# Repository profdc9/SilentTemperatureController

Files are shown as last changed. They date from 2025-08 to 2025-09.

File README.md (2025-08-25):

# Silent Temperature Controller

This is a heating temperature controller intended to minimize the vibrations caused by the heating element.  It uses kHz speed PWM modulated DC, rather than switching 50 or 60 cycle mains power, to power the heating elements.  For explosing holographic emulsions, the temperature must be stable and the vibrations must be minimized so that the sub-wavelength interference features are preserved.  By using high frequency PWM, the mechanical vibration or magnetostriction of the heating element coils is raised above a likely resonance frequency and therefore unlikely to cause significant vibrational movement.

The temperature controller can use up to three B3950 10k nominal resistance thermistors, or alternatively a LM335 temperature-based zener diode.  Reference thermistors may be added so that differential measurements can be taken to compensate for component temperature drift.  The controller supports up to four heating elements.  The DC power supply is up to 24 volts and 10 amps or so, with the limitation given by the trace width on the PCB.  If additional power bus wires are soldered in parallel with the traces, a higher current capacity is likely possible.  It is best to place the thermistors and heating elements in a vibration isolated, thermally insulated enclosure in which the hologram is exposed, with the enclosure being small enough so that the heaters can maintain a constant temperature throughout the volume.  A vibration-isolated platform may be achieved by placing a heavy cement slab or granite slab on partially inflated tires, and the granite slab may be made part of a thermally insulated enclosure using polystryrene slabs as walls.

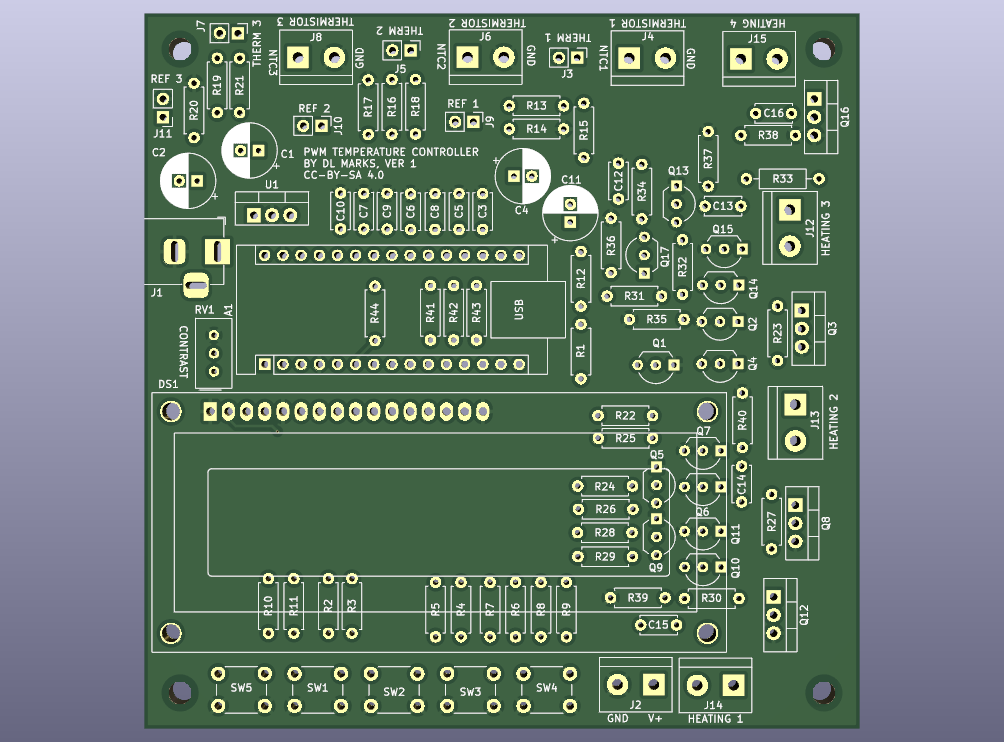
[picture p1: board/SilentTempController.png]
PCB


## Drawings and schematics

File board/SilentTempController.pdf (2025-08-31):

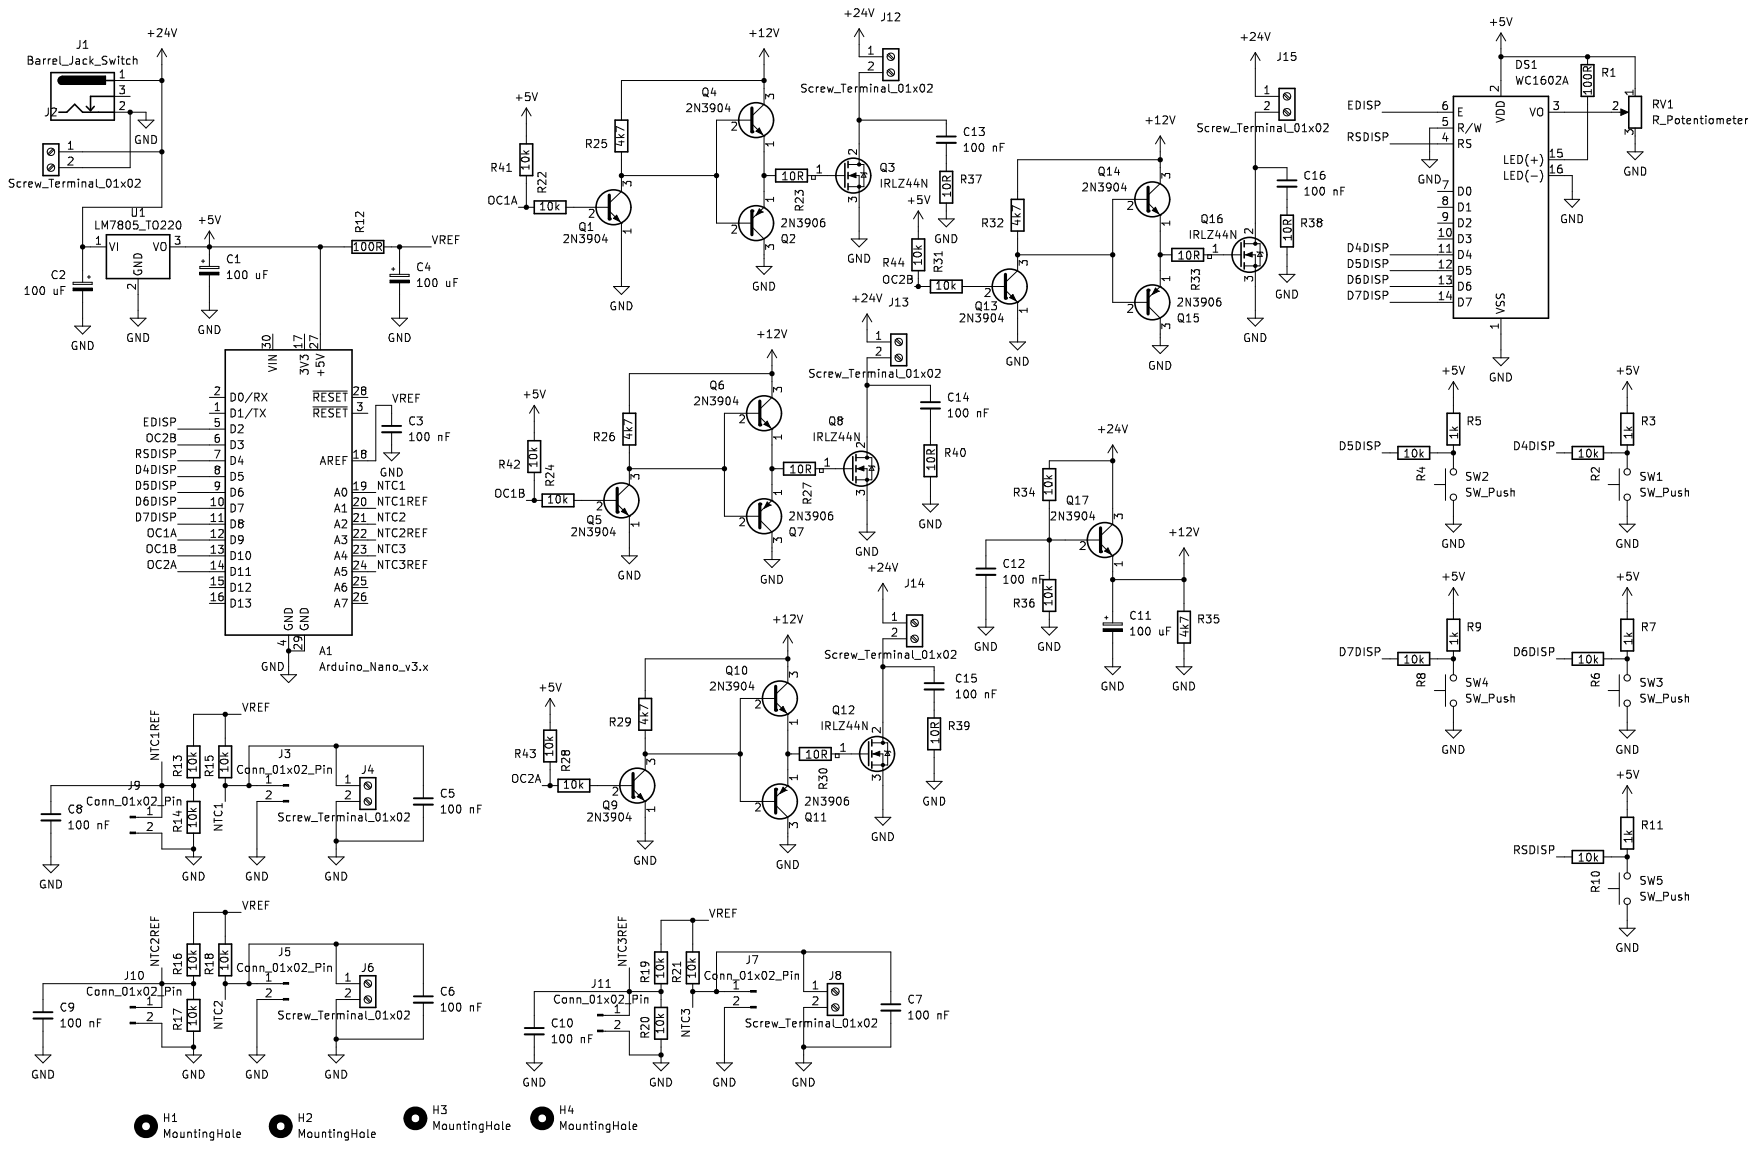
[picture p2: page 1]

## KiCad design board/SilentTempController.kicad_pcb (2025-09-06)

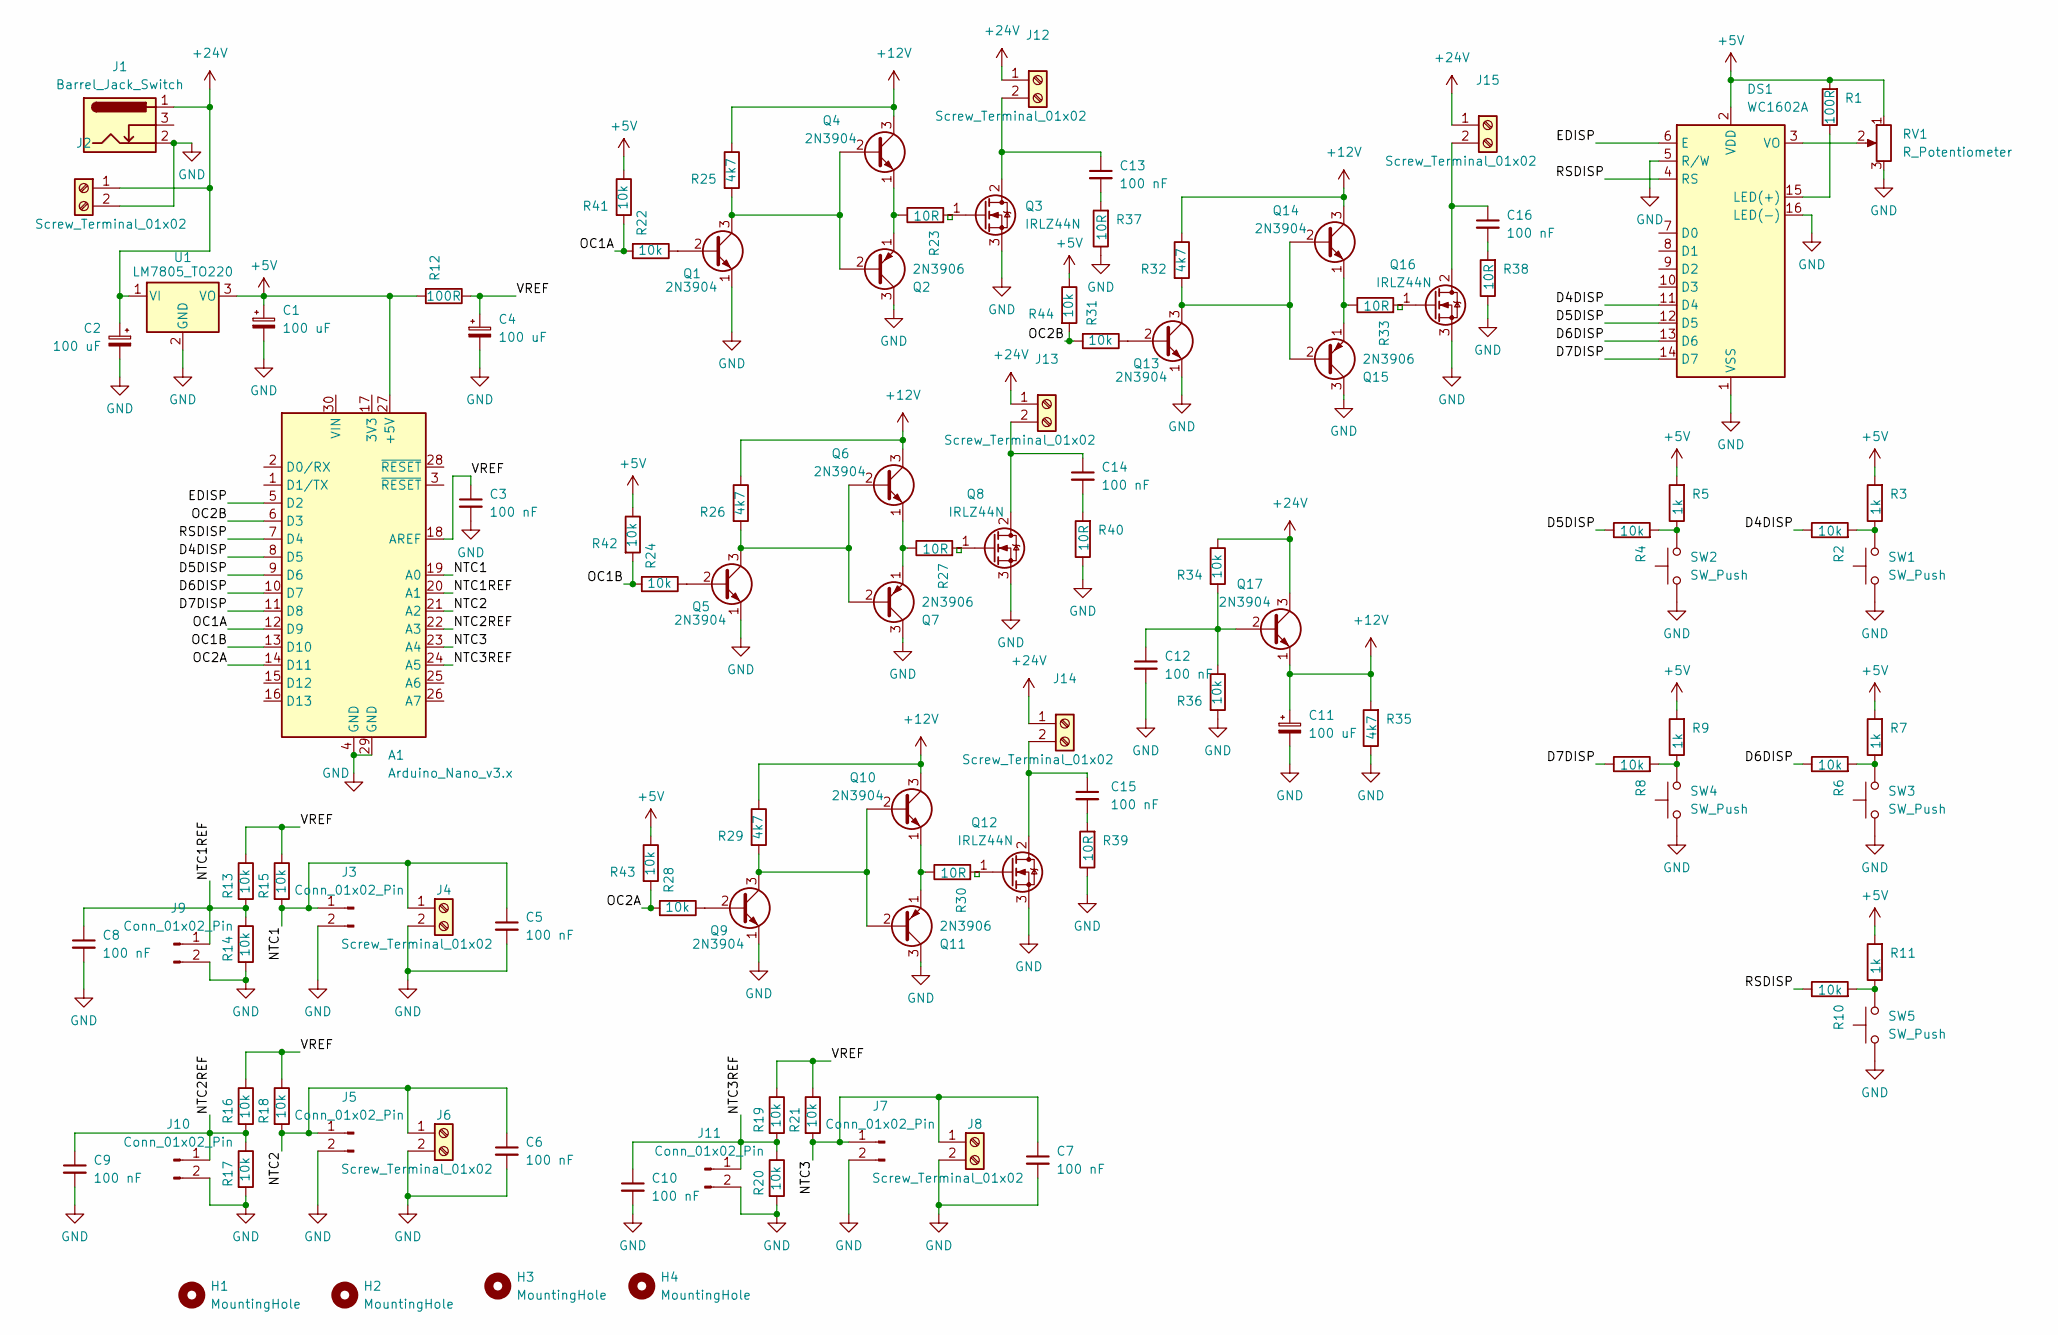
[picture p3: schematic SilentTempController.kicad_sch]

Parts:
A1: Arduino_Nano_v3.x; Arduino_Nano
C1, C2, C4, C11: 100 uF; CP_Radial_D7.5mm_P2.50mm
C3, C5, C6, C7, C8, C9, C10, C12, C13, C14, C15, C16: 100 nF; C_Disc_D5.0mm_W2.5mm_P5.00mm
DS1: WC1602A
H1, H2, H3, H4: MountingHole; MountingHole_3.2mm_M3
J1: Barrel_Jack_Switch; BarrelJack_Horizontal
J2, J4, J6, J8, J12, J13, J14, J15: Screw_Terminal_01x02; TerminalBlock_bornier-2_P5.08mm
J3, J5, J7, J9, J10, J11: Conn_01x02_Pin; PinHeader_1x02_P2.54mm_Vertical
Q1, Q4, Q5, Q6, Q9, Q10, Q13, Q14, Q17: 2N3904; TO-92_Inline_Wide
Q2, Q7, Q11, Q15: 2N3906; TO-92_Inline_Wide
Q3, Q8, Q12, Q16: IRLZ44N; TO-220-3_Vertical
R1, R12: 100R; R_Axial_DIN0207_L6.3mm_D2.5mm_P7.62mm_Horizontal
R2, R4, R6, R8, R10, R13, R14, R15, R16, R17, R18, R19, R20, R21, R22, R24, R28, R31, R34, R36, R41, R42, R43, R44: 10k; R_Axial_DIN0207_L6.3mm_D2.5mm_P7.62mm_Horizontal
R3, R5, R7, R9, R11: 1k; R_Axial_DIN0207_L6.3mm_D2.5mm_P7.62mm_Horizontal
R23, R27, R30, R37, R38, R39, R40: 10R; R_Axial_DIN0207_L6.3mm_D2.5mm_P7.62mm_Horizontal
R25, R26, R29, R32, R35: 4k7; R_Axial_DIN0207_L6.3mm_D2.5mm_P7.62mm_Horizontal
R33: 10R; R_Axial_DIN0207_L6.3mm_D2.5mm_P10.16mm_Horizontal
RV1: R_Potentiometer; Potentiometer_Bourns_3296W_Vertical
SW1, SW2, SW3, SW4, SW5: SW_Push; SW_PUSH_6mm
U1: LM7805_TO220; TO-220-3_Vertical

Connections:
+5V: A1.27 (+5V), C1.1, DS1.2 (VDD), R1.2, R3.2, R5.2, R7.2, R9.2, R11.2, R12.2, R41.1, R42.1, R43.1, R44.1, RV1.1, U1.3 (VO)
+12V: C11.1, Q4.3 (C), Q6.3 (C), Q10.3 (C), Q14.3 (C), Q17.1 (E), R25.1, R26.1, R29.1, R32.1, R35.2
+24V: C2.1, J1.1, J2.1, J12.1, J13.1, J14.1, J15.1, Q17.3 (C), R34.1, U1.1 (VI)
/D4DISP: A1.8 (D5), DS1.11 (D4), R2.1
/D5DISP: A1.9 (D6), DS1.12 (D5), R4.1
/D6DISP: A1.10 (D7), DS1.13 (D6), R6.1
/D7DISP: A1.11 (D8), DS1.14 (D7), R8.1
/EDISP: A1.5 (D2), DS1.6 (E)
/NTC1: A1.19 (A0), C5.1, J3.1, J4.1, R15.2
/NTC1REF: A1.20 (A1), C8.1, J9.1, R13.2, R14.1
/NTC2: A1.21 (A2), C6.1, J5.1, J6.1, R18.2
/NTC2REF: A1.22 (A3), C9.1, J10.1, R16.2, R17.1
/NTC3: A1.23 (A4), C7.1, J7.1, J8.1, R21.2
/NTC3REF: A1.24 (A5), C10.1, J11.1, R19.2, R20.1
/OC1A: A1.12 (D9), R22.2, R41.2
/OC1B: A1.13 (D10), R24.2, R42.2
/OC2A: A1.14 (D11), R28.2, R43.2
/OC2B: A1.6 (D3), R31.2, R44.2
/RSDISP: A1.7 (D4), DS1.4 (RS), R10.1
/VREF: A1.18 (AREF), C3.1, C4.1, R12.1, R13.1, R15.1, R16.1, R18.1, R19.1, R21.1
GND: A1.4 (GND), A1.29 (GND), C1.2, C2.2, C3.2, C4.2, C5.2, C6.2, C7.2, C8.2, C9.2, C10.2, C11.2, C12.2, DS1.1 (VSS), DS1.5 (R/W), DS1.16 (LED(-)), J1.2, J2.2, J3.2, J4.2, J5.2, J6.2, J7.2, J8.2, J9.2, J10.2, J11.2, Q1.1 (E), Q2.3 (C), Q3.3 (S), Q5.1 (E), Q7.3 (C), Q8.3 (S), Q9.1 (E), Q11.3 (C), Q12.3 (S), Q13.1 (E), Q15.3 (C), Q16.3 (S), R14.2, R17.2, R20.2, R35.1, R36.2, R37.1, R38.1, R39.1, R40.1, RV1.3, SW1.1, SW2.1, SW3.1, SW4.1, SW5.1, U1.2 (GND)
unnamed: C13.2, R37.2
unnamed: C14.2, R40.2
unnamed: C15.2, R39.2
unnamed: C16.2, R38.2
unnamed: DS1.15 (LED(+)), R1.1
unnamed: DS1.3 (VO), RV1.2
unnamed: C13.1, J12.2, Q3.2 (D)
unnamed: C14.1, J13.2, Q8.2 (D)
unnamed: C15.1, J14.2, Q12.2 (D)
unnamed: C16.1, J15.2, Q16.2 (D)
unnamed: Q1.2 (B), R22.1
unnamed: Q1.3 (C), Q2.2 (B), Q4.2 (B), R25.2
unnamed: Q2.1 (E), Q4.1 (E), R23.1
unnamed: Q3.1 (G), R23.2
unnamed: Q5.2 (B), R24.1
unnamed: Q5.3 (C), Q6.2 (B), Q7.2 (B), R26.2
unnamed: Q6.1 (E), Q7.1 (E), R27.1
unnamed: Q8.1 (G), R27.2
unnamed: Q9.2 (B), R28.1
unnamed: Q9.3 (C), Q10.2 (B), Q11.2 (B), R29.2
unnamed: Q10.1 (E), Q11.1 (E), R30.1
unnamed: Q12.1 (G), R30.2
unnamed: Q13.2 (B), R31.1
unnamed: Q13.3 (C), Q14.2 (B), Q15.2 (B), R32.2
unnamed: Q14.1 (E), Q15.1 (E), R33.1
unnamed: Q16.1 (G), R33.2
unnamed: C12.1, Q17.2 (B), R34.2, R36.1
unnamed: R2.2, R3.1, SW1.2
unnamed: R4.2, R5.1, SW2.2
unnamed: R6.2, R7.1, SW3.2
unnamed: R8.2, R9.1, SW4.2
unnamed: R10.2, R11.1, SW5.2

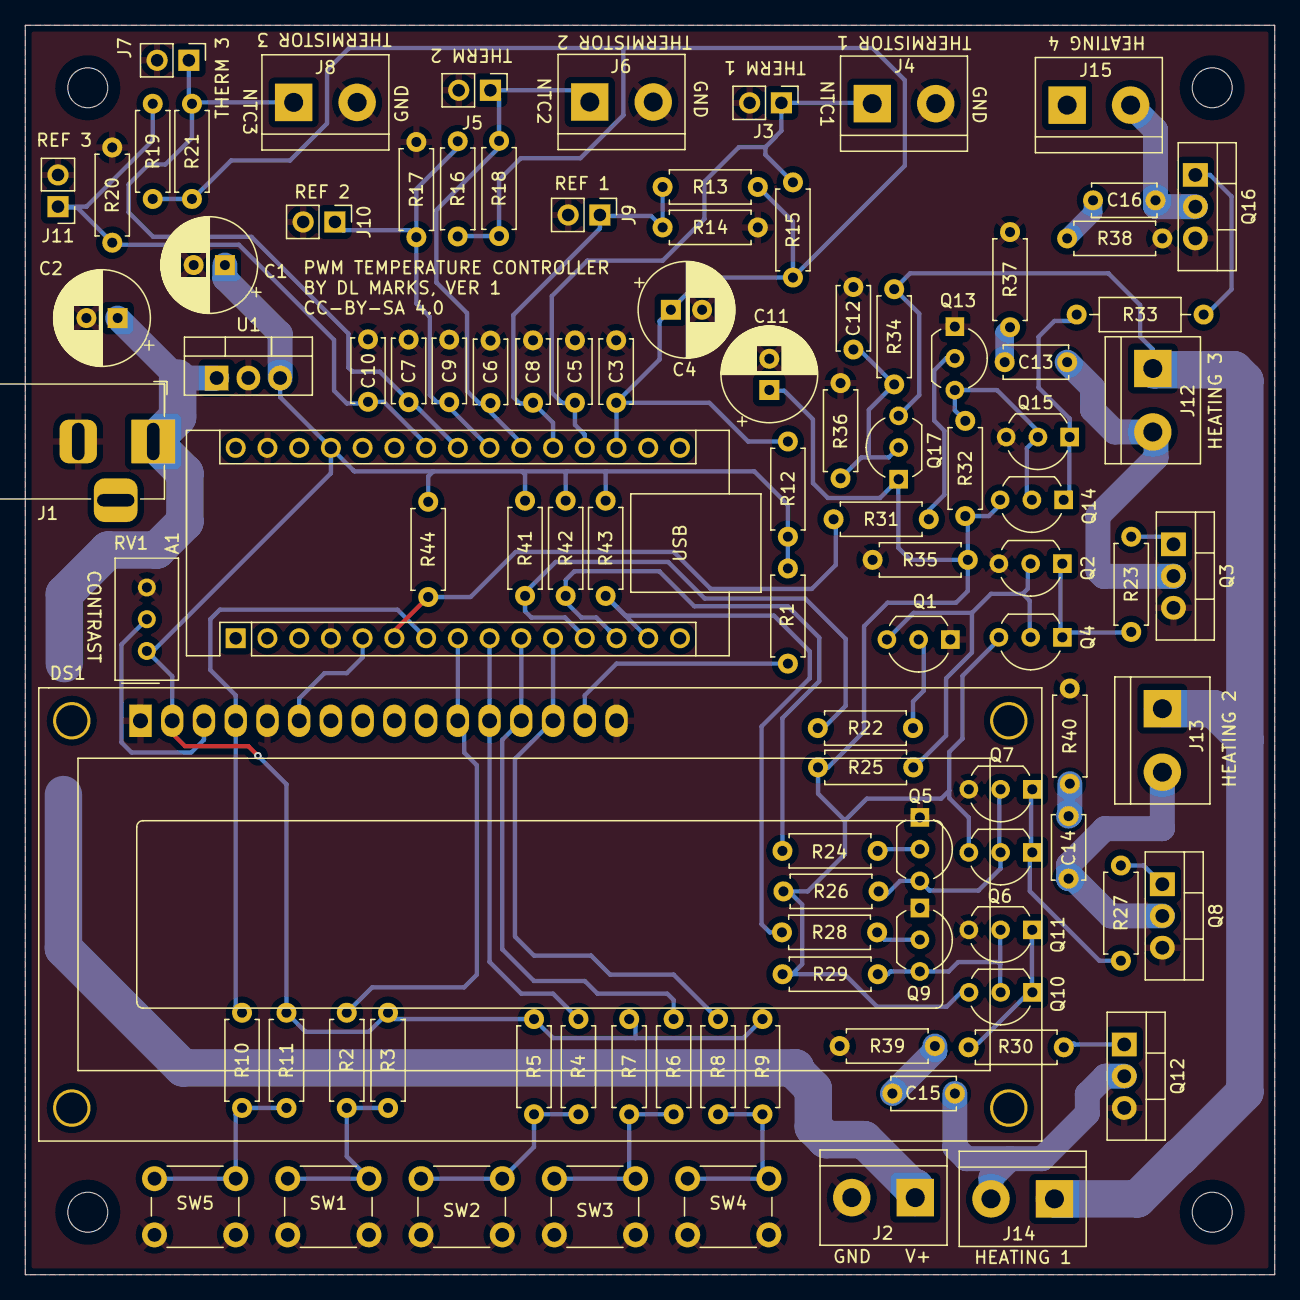
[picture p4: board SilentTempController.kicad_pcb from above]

Board: 2 copper layers, 100.0 x 100.0 mm, 105 parts (0 on the bottom side), 53 nets.

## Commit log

2025-08-26 Added snubbers
    [MOSFETdriver.sch, SilentTempController.kicad_pcb, SilentTempController.kicad_sch]
2025-08-26 moved connectors
    [SilentTempController-B_Cu.gbr, SilentTempController-B_Mask.gbr, SilentTempController-B_Paste.gbr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]
2025-08-30 improved snubbers
    [MOSFETdriver.sch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]
2025-08-31 Added on protection
    [SilentTempController-B_Cu.gbr, SilentTempController-B_Mask.gbr, SilentTempController-B_Paste.gbr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]
2025-09-06 JLCPCB order
    [SilentTempController-B_Cu.gbr, SilentTempController-B_Mask.gbr, SilentTempController-B_Paste.gbr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]

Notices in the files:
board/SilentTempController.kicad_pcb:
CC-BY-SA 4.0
